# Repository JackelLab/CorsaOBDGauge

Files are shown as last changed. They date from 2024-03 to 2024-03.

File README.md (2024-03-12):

Bluetooth OBD Based Gauge For The Vauxhall/Opel Corsa

Anyone who owns an early Corsa knows you can't show the battery percentage on the dash
without having the car plugged in to a charger. The only other way is using an app on
your phone connected to and Bluetooth OBD adaptor (or WiFi adaptor if you have an iphone).

The problem with using an app (like 'Car Scanner' is that you need to connect to the
adaptor and then the car every time you want to see the data.

I decided (too long ago) that I wanted to make a display which showed the battery
percentage so it was always visible. My biggest stumbling block to this was understanding
what requests to send to the car and how to decode this data. After sometime, I found
some details on another github page 'EVNotify' which mentioned what data needed to be
sent and what the responses would be:
https://github.com/EVNotify/EVNotify/issues/205

With this information, I was finally able to get access to the data from the car.

I built a PCB with an ESP32-WROVER-IE as the main processor as it has Bluetooth built in,
a 0.96" LCD from ebay with 160 x 80 pixel 65k colours.

The features I've added so far are:

SOC        - Battery state of charge. I've used the non calibrated version, I don't know
what the differences are.

SOH        - Battery state of health. This only shows after the unit has setup and
checked communications with the OBD adaptor and car.

SOC Delta  - State of charge change. This shows to SOC change since the unit was powered
up, ideal for tracking how much battery has been used for a journey or how much battery
has been added while charging.

Temperature - Battery temperature.

Speed       - Shows the speed in 100th of MPH which can be re-calibrated if measured
against a GPS speedo.

Voltage     - OBD 12V battery voltage. Measured at the OBD adaptor.

Est. Range  - Estimated range based on speed and battery percentage used over the last
minute and 5 minutes.

There is a reed switch to change the display modes, the gauge will remember the last mode
and restore it at power up.

The ELM327 OBD.

When selecting a Bluetooth OBD adaptor, you will need to find one with the PIC18F25K80
chip. May of the adaptors for sale will say they are PIC versions, but often, they are
emulated versions and for whatever reason, the ESP32 can't communicate correctly with
them and just receives echoed data back.

So, ELM Electronics created the ELM327 chip for communicating with the OBD port on
vehicles, but with their version 1.5 software, chips where sent out without the code
protection on and so this code has been copied by may of the Chinese manufactures making
the currently available adaptors. If the adaptor you are looking to buy has any mention of
V2.1, then it is more likely a chip pretending to be a PIC.

The only way to really confirm that the adaptor has a PIC chip in it is to pop it open and
check.

My code requires you to put in the MAC address of the OBD adaptor, here are 2 ways you can
find the MAC address. Use an ESP32 to scan for Bluetooth devices and report the addresses
( https://github.com/esp32beans/ESP32-BT-exp ) or pair with a windows machine and get the
MAC address from the device details.

The alternative way, would be to use WiFi versions of the adaptor. At the moment, I've not
done any development on this method but may look into it in the future.

Another thing to note, not all adaptors have the correct resistors to do voltage
measurement and some that do, may not have been calibrated. Check the voltage with a volt
meter and compare that with the adaptor. Calibration would need to be done through a
computer with a terminal program.

Currently, the enclosure you can download is just a simple cover to hide and protect the
board, a friend is currently trying to map the instrument cluster to make a neater, almost
factory style, cover for the board which will sit to the right of the current instrument
cluster.

WIP..

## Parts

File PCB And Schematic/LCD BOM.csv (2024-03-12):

Ref | Desc | Package | Qty | PN | Manu | Notes
C1,C3-C4,C7-C8 | 100nF Capacitor 50V | 0603 | 5 | Any | Any
C2 | 10uF Capacitor 25V X5R | 0603 | 1 | Any | Any
C5-C6 | 22uF Capacitor 6.3V X5R | 0603 | 2 | Any | Any
CON1 | 3 Way RA Pin Header |  | 1 | TSM-102-01-T-SH | Samtec | Can solder wires to pads instead
CON2 | Tag 6 Pin Programming Header |  | NF
IC1 | 3.3V FixedBuck Regulator | TSOT-26-6 | 1 | AP63203WU-7 | Diodes Inc
L1 | 6.8uH Inductor |  | 1 | LQH3NPN6R8MMEL | MURATA | Or equivelent with same footprint
LCD1 | ST7735 0.96" 160x80 Pixel LCD (Solder Type) |  | 1 | LH096NT-IG11G | Limito | Soldered direct to the board
MOD1 | ESP32-Wrover |  | 1 | ESP32-WROVER-IE 8MB | Expressif
R1-R6,R8 | 10K 1% Resistor | 0603 | 7 | Any | Any
R7 | 1K 1% Resistor | 0603 | 1 | Any | Any
R9 | 10R 1% Resistor | 0603 | 1 | Any | Any
Rx | 0R Link | 0201 | 1 | Any | Any | Used to replace the link on the ESP32 Module
SW1 | Reed Switch |  | 1 | MASM-14R-10-15 | Littelfuse
TR1-TR2 | N-Channel Power MOSFET | SOT23 | 2 | DMG2302U-7 | Dides Inc

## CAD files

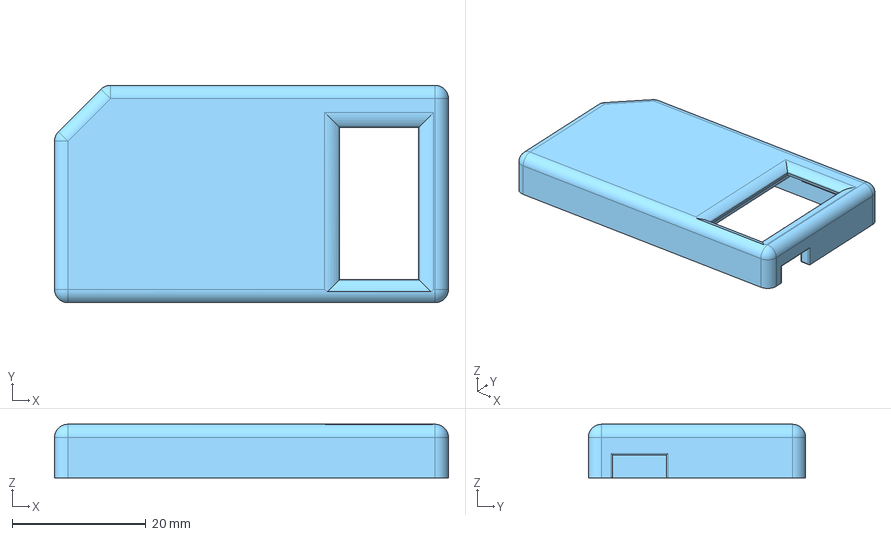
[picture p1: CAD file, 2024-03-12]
3D Files/Corsa Gauge.stp
58.8 x 32.5 x 8.00 mm

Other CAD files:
3D Files/Corsa Gauge.stl

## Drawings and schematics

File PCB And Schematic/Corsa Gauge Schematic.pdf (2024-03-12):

# 0V⁺³V³

A

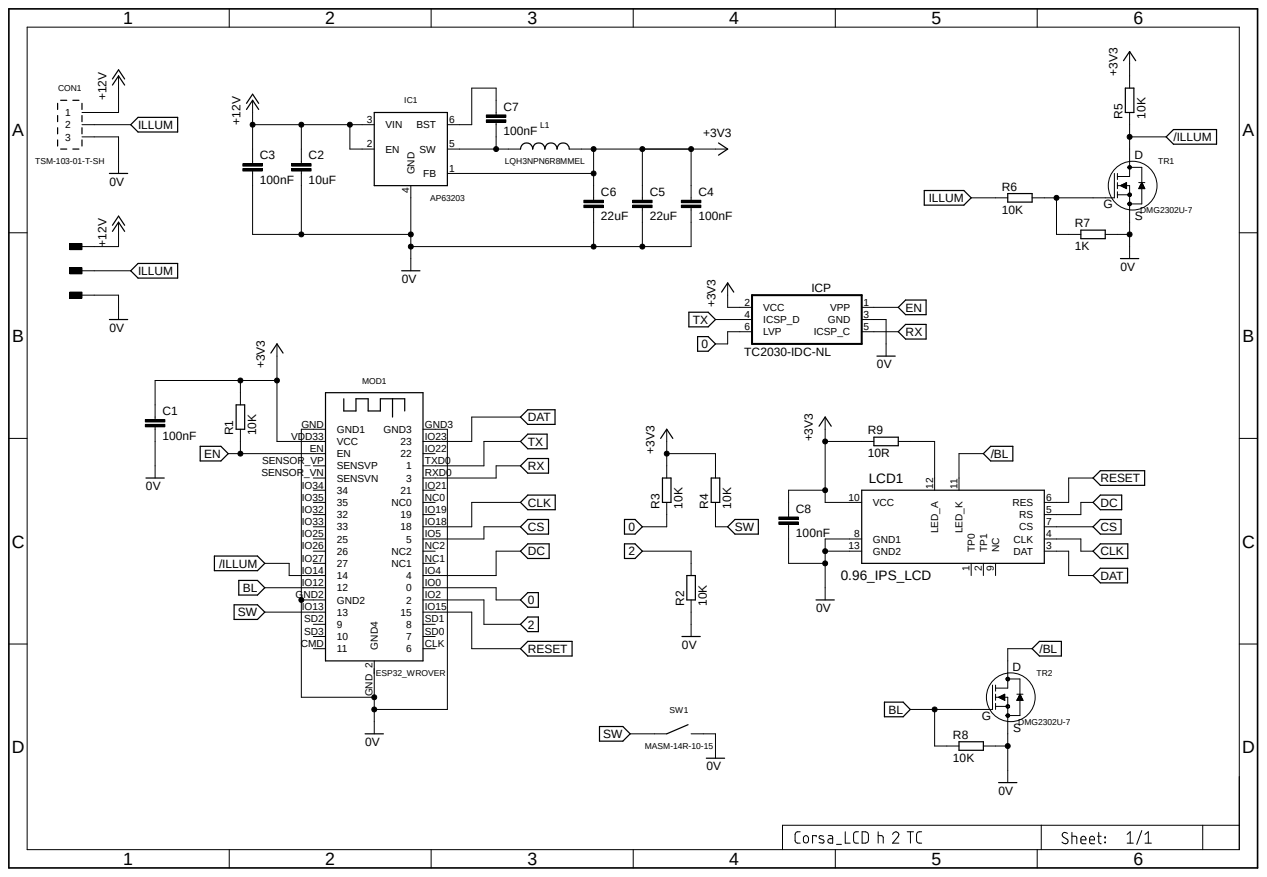
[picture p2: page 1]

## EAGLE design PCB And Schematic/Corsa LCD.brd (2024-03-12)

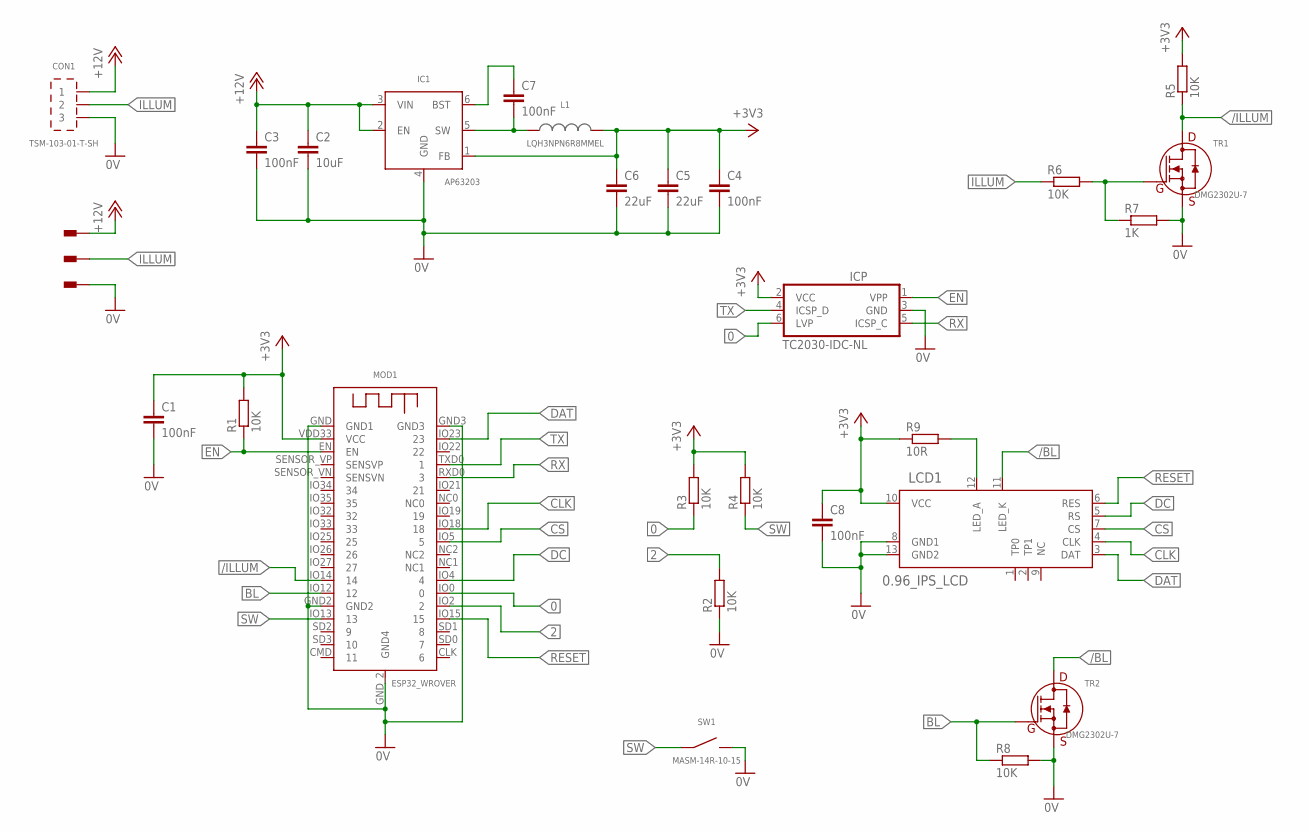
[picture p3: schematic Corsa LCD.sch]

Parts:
C1, C3, C4, C7, C8: 100nF; C0603
C2: 10uF; C0603
C5, C6: 22uF; C0603
CON1: TSM-103-01-T-SH
IC1: AP63203; TSOT26
ICP: TC2030-IDC-NL
L1: LQH3NPN6R8MMEL; LQH3NPN
LCD1: 0.96_IPS_LCD
MOD1: ESP32_WROVER; ESP32_WROOVER
PIN1, PIN2, PIN3: SOLDERPAD
R1, R2, R3, R4, R5, R6, R8: 10K; R0603
R7: 1K; R0603
R9: 10R; R0603
SW1: MASM-14R-10-15; MASM-14
TR1, TR2: DMG2302U-7; SOT23

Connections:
0: ICP.6 (LVP), MOD1.IO0 (0), R3.1
0V: C1.2, C2.2, C3.2, C4.2, C5.2, C6.2, C8.2, CON1.3, IC1.4 (GND), ICP.3 (GND), LCD1.8 (GND1), LCD1.13 (GND2), MOD1.GND (GND1), MOD1.GND2, MOD1.GND3, MOD1.GND_2 (GND4), PIN3.1, R2.1, R7.2, R8.2, SW1.2, TR1.2 (S), TR2.2 (S)
2: MOD1.IO2 (2), R2.2
+3V3: C1.1, C4.1, C5.1, C6.1, C8.1, IC1.1 (FB), ICP.2 (VCC), L1.2, LCD1.10 (VCC), MOD1.VDD33 (VCC), R1.2, R3.2, R4.2, R5.2, R9.1
+12V: C2.1, C3.1, CON1.1, IC1.2 (EN), IC1.3 (VIN), PIN1.1
/BL: LCD1.11 (LED_K), TR2.3 (D)
/ILLUM: MOD1.IO14 (14), R5.1, TR1.3 (D)
BL: MOD1.IO12 (12), R8.1, TR2.1 (G)
CLK: LCD1.4 (CLK), MOD1.IO18 (18)
CS: LCD1.7 (CS), MOD1.IO5 (5)
DAT: LCD1.3 (DAT), MOD1.IO23 (23)
DC: LCD1.5 (RS), MOD1.IO4 (4)
EN: ICP.1 (VPP), MOD1.EN, R1.1
ILLUM: CON1.2, PIN2.1, R6.1
unnamed: LCD1.12 (LED_A), R9.2
unnamed: R6.2, R7.1, TR1.1 (G)
unnamed: C7.1, IC1.6 (BST)
unnamed: C7.2, IC1.5 (SW), L1.1
RESET: LCD1.6 (RES), MOD1.IO15 (15)
RX: ICP.5 (ICSP_C), MOD1.RXD0 (3)
SW: MOD1.IO13 (13), R4.1, SW1.1
TX: ICP.4 (ICSP_D), MOD1.TXD0 (1)

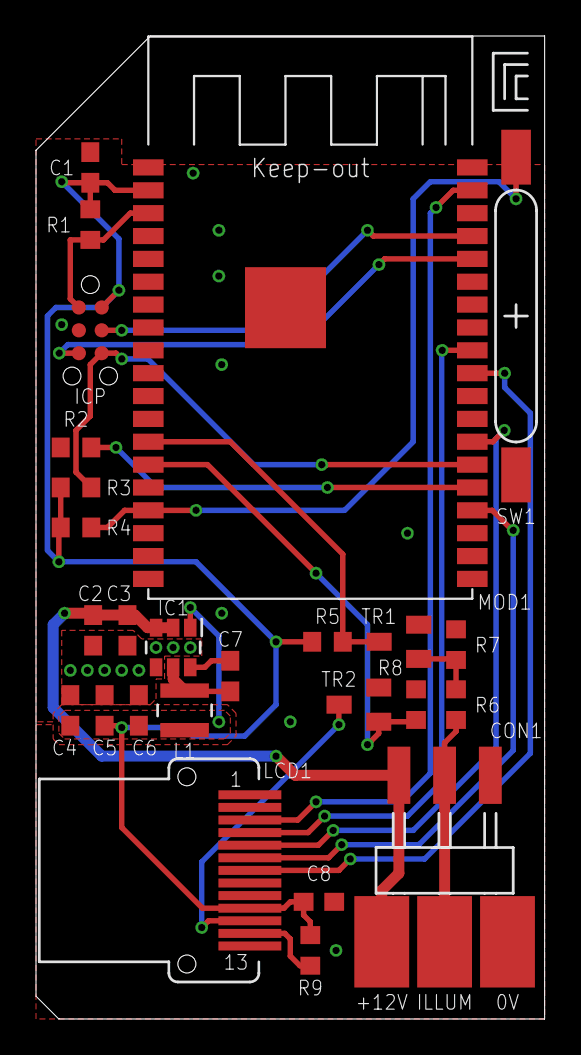
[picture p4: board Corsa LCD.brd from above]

Board: 2 copper layers, 28.3 x 54.6 mm, 29 parts (0 on the bottom side), 22 nets.

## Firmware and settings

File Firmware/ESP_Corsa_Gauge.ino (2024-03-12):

// ======================================================================================
// 
//          ESP32 Based Corsa-e Battery SOC Gauge And More Created By C. Curtis
// https://github.com/JackelLab/CorsaOBDGauge
//
// Copyright (c) 2024 C.Curtis/JackelLab
//
// I offer these files for you to use, for personal use, free of charge. You may copy
// these files, modify and reupload these files providing you are not using them for
// financial gain and must include the header and details of where the original files
// maybe downloaded.
//
// Anyone wishing to use these files for financial gain, must request permission to do so.
//
// The libraries used within the software are copyright by their relevant owners and
// separate permission will have to be gained through them.
//
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
// ======================================================================================


// ======================================================================================
// Version
// ======================================================================================
// beta - First release to github

// ======================================================================================
// Possible Future Features
// ======================================================================================
// Select between SOC and SOC calibrated
// Journey based range estimate
// Reset delta without having to turn power off
// Software selection of bluetooth MAC address instead of hard coding or automatic search

// ======================================================================================
// Options
// ======================================================================================

#define BackLightDim 127    // PWM level when illumination input is high
#define BackLightBright 255 // PWM level when illumination input is low
#define SOHDelay 1200       // Delay time to allow SOH to be seen
#define RefreshPeriod 1000  // Time in mS for main loop

#define BTMODULE 1          // 0 - No BT module, 1 - BT module
#define DEMOMODE 0          // 0 - Normal mode, 1 - Demo mode

// When demomode = 1, use the following values at the start
#define DemoSOH 87.6;
#define DemoSOC 91.01;
#define DemoSOCDelta 100.0;
#define DemoTemperature 12;
#define DemoVoltage 13.8;
#define DemoSpeed 0.0;

#define LCDOrientation 1    // 1 is newer PCB, 3 is older (aplha) PCB

#define SpeedCorrection 208

// --------------------------------------------------------------------------------------
// Colour Options
// --------------------------------------------------------------------------------------

#define SOCGood TFT_WHITE
#define SOCOk TFT_YELLOW
#define SOCBad TFT_RED
#define SOCOkLevel 10
#define SOCBadLevel 2

#define TempHot TFT_RED
#define TempCaution 0xFFE0              // Yellow
#define TempOk TFT_WHITE
#define TempCold 0x03FF                 // Cyanish blue
#define TempHotLevel 50
#define TempCautionLevel 40
#define TempColdLevel 2

#define DeltaSOCPlus TFT_GREEN
#define DeltaSOCNegative 0xFC10         // Whiter red

#define SOHGood TFT_WHITE
#define SOHOk TFT_WHITE
#define SOHBad TFT_YELLOW
#define SOHFlagPole TFT_WHITE
#define SOHFlagColour TFT_BLUE
#define SOHOkLevel 80
#define SOHBadLevel 50

#define VoltageHigh TFT_RED
#define VoltageCautionHigh TFT_YELLOW
#define VoltageGood TFT_GREEN
#define VoltageOk TFT_WHITE
#define VoltageLow TFT_YELLOW
#define VoltageLowBad TFT_RED
#define VoltageHighLevel 15.0
#define VoltageCautionHighLevel 14.6
#define VoltageOkLevel 13.8
#define VoltageLowLevel 12.5
#define VoltageLowBadLevel 12.0

#define InvalidDataColour TFT_RED

// Colours are a 16 bit number in the format of 5-6-5. 5 red bits, 6 green and 5 blue.
// Red is 0xF800, green is 0x07E0, blue is 0x001F

// ======================================================================================
// Includes
// ======================================================================================

#include <Arduino.h>
#include "SPI.h"
#include "TFT_eSPI.h"
#include "Free_Fonts.h"

#include "Icons.h"

// EEPROM include and definitions
#include <EEPROM.h>
#define EEPROM_SIZE 64

// ======================================================================================
// Definitions
// ======================================================================================

// Use hardware SPI
TFT_eSPI tft = TFT_eSPI();
TFT_eSprite page = TFT_eSprite(&tft);

// Bluetooth setup
#if BTMODULE == 1
// Bluetooth includes
#include "BluetoothSerial.h"
BluetoothSerial SerialBT;
uint8_t OBDAddress[6]  = {0x01, 0x02, 0x03, 0x04, 0x05, 0x06};  // OBD MAC address
#endif

// Test positions
#define ROW1L 36
#define ROW2L 76
#define ROW2S 73

#define NoOfModes 9
// Modes:
// 0 - TL = SOC, BL = Temperature and SOC Delta
// 1 - TL = SOC, BL = Range 1 and SOC Delta
// 2 - TL = SOC, BL = Range 1 and Speed
// 3 - TL = SOC, BL = Temperature and Speed
// 4 - TL = SOC, BL = Range 1 and Range 5
// 5 - TL = SOC, BL = Temperature and 12V Battery
// 6 - TL = SOC, BL = 12V Battery and SOC Delta
// 7 - TL = SOC, BL = 12V Battery and Speed
// 8 - TL = SOC, BL = Speed

// Distance covered by traveling at 1mph for 1 second
#define SpeedFactor 0.000277777

// ======================================================================================
// Icon Location Definitions (Splash Screen)
// ======================================================================================

#define BTx 68
#define BTy 20
#define CPUx 0
#define CPUy 24
#define CARx 128
#define CARy 24

// ======================================================================================
// IO defintions
// ======================================================================================

#define BackLight 12      // LCD Backlight output pin
#define Button 13         // Reed switch input
#define Illumination 14   // Illumination control input

// ======================================================================================
// Comms Details
// ======================================================================================

#define CommsTimeOut 3000                   // Time in mS (General comms timeout)
#define SearchingTimeOut 10000              // Time in mS (timeout after issuing a reset)

// ======================================================================================
// Variables
// ======================================================================================

#if DEMOMODE == 1
// Demo mode variables with preset values
float SOC = DemoSOC;
int SOCDemoMode = 0;
float StartSOC = DemoSOCDelta;
float SOH = DemoSOH;
bool SOHFlag = true;
uint16_t Speed;
float SpeedF = DemoSpeed;
int Temperature = DemoTemperature;
float BatteryVoltage = DemoVoltage;
bool SpeedDirection = false;
#else
float SOC;
float StartSOC;
float SOH;
bool SOHFlag = false;
uint16_t Speed;
float SpeedF;
int Temperature;
float BatteryVoltage;
#endif

char ReceiveBuff[48];     // Buffer has to be big enough to hold
                          //  SEARCHING... dUNABLE TO CONNECT dd>
uint8_t ReceiveBuffCount = 0;

float dSOC;
bool LastBacklight;
bool IlluminationInput;
bool Stuck;
uint16_t tp;
bool Timeout;
bool ValidData;
unsigned long LastUpdate;

bool ModeChange = false;
bool ModeChangeInput;
uint8_t Mode = 0;
bool UseEEPROM;

float BufferD[300];
float BufferP[300];
uint16_t Pointer1 = 0;
uint16_t Pointer5 = 0;
uint16_t PointerMax = 0;
float Distance1 = 0.0;
float Distance5 = 0.0;
float Percent1 = 0.0;
float Percent5 = 0.0;
float Range1;
float Range5;
int Range;
float t;
uint16_t n;

// ======================================================================================
// Main Routine
// ======================================================================================

void setup()
{
  // Use serial for debugging and logging
  Serial.begin(115200);
  
  // Setup IO
  //pinMode(Button, INPUT);
  pinMode(Button, INPUT_PULLUP);
  pinMode(Illumination, INPUT);
  
  // Setup LCD using TFT eSPI
  tft.init();
  tft.setRotation(LCDOrientation);  // 3 is older design, 1 is newer design
  tft.fillScreen(TFT_BLACK);
  tft.setTextSize(1);

  // Setup backlight using PWM
  ledcSetup(1, 1000, 8);        // Setup PWM channel
  ledcAttachPin(BackLight, 1);  // Assign backlight to channel
  // Check Illumination input and set backlight as approprate
  if(digitalRead(Illumination) == LOW)
  {
    ledcWrite(1, BackLightDim);
    LastBacklight = true;
  }
  else
  {
    ledcWrite(1, BackLightBright);
    LastBacklight = false;
  }

  // Load last mode from EEPROM 
  if(!EEPROM.begin(EEPROM_SIZE))
  {
    // Starting EEPROM failed so don't use it
    UseEEPROM = false;
  }
  else
  {
    UseEEPROM = true;
    // Is the EEPROM already setup?
    if((uint8_t) EEPROM.read(0) != 'M')
    {
      // EEPROM is not setup
      EEPROM.write(0, 'M');
      EEPROM.write(1, Mode);
      EEPROM.commit();
    }
    Mode = EEPROM.read(1);
  }
  
  // Setup page for quick drawing on the LCD
  //page.setAttribute(PSRAM_ENABLE, true);
  page.createSprite(160, 80);
  
  // Draw icon's and a bar showing communication point
  //tft.fillScreen(TFT_BLACK);
  tft.pushImage(BTx, BTy, 25, 39, BT_G, TFT_BLACK);
  tft.pushImage(CPUx, CPUy, 32, 32, CPU, TFT_BLACK);
  tft.pushImage(CARx, CARy, 32, 32, CAR, TFT_BLACK);
  tft.fillRect(CPUx + 34, 38, BTx - CPUx - 36, 4, TFT_WHITE);
  
#if BTMODULE == 1
  // Bluetooth serial and ODB stuff
  SerialBT.setPin("1234");
  SerialBT.begin("Corsa-e", true);
  
  // Try and connect to OBD via bluetooth serial
  Stuck = true;
  while(Stuck)
  {
    if(!SerialBT.connect(OBDAddress))
    {
      // Can't connect to OBDII device, show message.
      tft.pushImage(BTx, BTy, 25, 39, BT_R, TFT_BLACK);
      tft.fillRect(CPUx + 34, 38, BTx - CPUx - 36, 4, TFT_RED);
      delay(1000);
    }
    else
    {
      // Connected, exit the loop
      Stuck = false;
    }
  }
  // Show that chip to BT module is successful
  tft.fillRect(CPUx + 34, 38, BTx - CPUx - 36, 4, TFT_GREEN);
  Serial.println("BT Connected");
  // BT icon to blue
  tft.pushImage(BTx, BTy, 25, 39, BT_B, TFT_BLACK);
  // Show new communication point, BT to car
  tft.fillRect(BTx + 27, 38, CARx - BTx - 29, 4, TFT_WHITE);
  
  // Communicate with OBD II, start with reset command
  Stuck = true;
  while(Stuck)
  {
    Timeout = SendOBD("ATZ", SearchingTimeOut);
    if(ReceiveBuffCount == 0 || Timeout)
    {
      // Couldn't talk to ELM327
      // Show red bluetooth icon?
      //tft.pushImage(BTx, BTy, 25, 39, BT_R, TFT_BLACK);
      // Show red line
      tft.fillRect(BTx + 27, 38, CARx - BTx - 29, 4, TFT_RED);
      delay(2000);
    }
    else
    {
      Stuck = false;
    }
  }
  // Clear the line to show communication steps
  tft.fillRect(BTx + 27, 38, CARx - BTx - 29, 4, TFT_BLACK);
  
  // Setup and start OBD
  Timeout = SendOBD("ATE0", CommsTimeOut);    // Echo off
  tft.fillRect(BTx + 27, 38, 2, 4, TFT_GREEN);
  
  Timeout = SendOBD("ATH1", CommsTimeOut);    // Headers on
  tft.fillRect(BTx + 30, 38, 2, 4, TFT_GREEN);
  
  Timeout = SendOBD("ATS0", CommsTimeOut);    // Spaces off
  tft.fillRect(BTx + 33, 38, 2, 4, TFT_GREEN);
  
  Timeout = SendOBD("ATM0", CommsTimeOut);    // Memory off
  tft.fillRect(BTx + 36, 38, 2, 4, TFT_GREEN);
  
  Timeout = SendOBD("ATSPA6", CommsTimeOut);   // Protocol automatic 6
  tft.fillRect(BTx + 39, 38, 2, 4, TFT_GREEN);
  
  Timeout = SendOBD("ATAT1", CommsTimeOut);    // Adaptive timing auto1
  tft.fillRect(BTx + 42, 38, 2, 4, TFT_GREEN);
  
  Timeout = SendOBD("ATSH6B4", CommsTimeOut);    // Set header 6B4 (this has SOC and SOH)
  tft.fillRect(BTx + 45, 38, 2, 4, TFT_GREEN);
  
  Timeout = SendOBD("ATFCSH6B4", CommsTimeOut);    // Flow control set header 6B4
  tft.fillRect(BTx + 48, 38, 2, 4, TFT_GREEN);
  
  Timeout = SendOBD("ATFCSD300000", CommsTimeOut);    // Set data to 300000
  tft.fillRect(BTx + 51, 38, 2, 4, TFT_GREEN);
  
  Timeout = SendOBD("ATFCSM1", CommsTimeOut);    // Flow control mode 1
  tft.fillRect(BTx + 54, 38, 2, 4, TFT_GREEN);
  
  Timeout = SendOBD("ATCRA694", CommsTimeOut);    // Receive address 694
#endif
#if DEMOMODE == 0
  // Get SOC
  Timeout = SendOBD("22D410", CommsTimeOut);    // Request SOC
  // Reply example 6940562D410ABA8dd>
  ValidData = true;
  // Check reply is valid
  if(ReceiveBuff[8] == 0x34 && ReceiveBuff[9] == 0x31 && ReceiveBuff[10] == 0x30 && Timeout == false)
  {
    // Valid data
    tp = Hex2Dec(ReceiveBuff[11], ReceiveBuff[12]);
    tp = (tp * 256) + Hex2Dec(ReceiveBuff[13], ReceiveBuff[14]);
    SOC = ((float) tp) / 512.0;
  }
  else
  {
    // Invalid data
    SOC = 0.0;
    ValidData = false;
  }
  // Copy SOC for delta SOC
  StartSOC = SOC;
  
  // Get SOH (we will only show this once)
  Timeout = SendOBD("22D860", CommsTimeOut);    // Request SOH
  // Reply example 6940562D8600105EDdd>
  // Check reply is valid
  if(ReceiveBuff[8] == 0x38 && ReceiveBuff[9] == 0x36 && ReceiveBuff[10] == 0x30 && Timeout == false)
  {
    // Valid data
    tp = Hex2Dec(ReceiveBuff[13], ReceiveBuff[14]);
    tp = (tp * 256) + Hex2Dec(ReceiveBuff[15], ReceiveBuff[16]);
    SOH = ((float) tp) / 16.0;
    if(ReceiveBuff[12] != 0x30)
    {
      SOHFlag = true;
      // Not sure what this flag is for
    }
  }
  else
  {
    // Invalid data
    SOH = 0.0;
    ValidData = false;
  }

  // Switch to 6A2/682 for battery temperature
  Timeout = SendOBD("ATSH6A2", CommsTimeOut);    // Set header 6A2
  Timeout = SendOBD("ATFCSH6A2", CommsTimeOut);    // Flow control set header 6A2
  Timeout = SendOBD("ATCRA682", CommsTimeOut);    // Receive address 682
  
  // Get battery temperature
  Timeout = SendOBD("22D8EF", CommsTimeOut);    // Request Temperature
  // Check if reply is valid
  if(ReceiveBuff[8] == 0x38 && ReceiveBuff[9] == 0x45 && ReceiveBuff[10] == 0x46 && Timeout == false)
  {
    // Valid data
    Temperature = (int) (Hex2Dec(ReceiveBuff[11], ReceiveBuff[12]));
    // If bit 7 is set (128-255), it's negative
    if(Temperature > 127)
    {
      // Make it negative
      Temperature = Temperature - 256;
    }
  }
  else
  {
    // Invalid data
    Temperature = 0;
    ValidData = false;
  }
#else
  tft.fillRect(BTx + 27, 38, CARx - BTx - 29, 4, TFT_GREEN);
  delay(500);
  ValidData = true;
#endif
    
  // If we have valid data, show the SOH
  if(ValidData == true)
  {
    DisplaySOH();
  }
  else
  {
    DisplayBadData();
  }
  // Delay for a moment so SOH can be read
  delay(SOHDelay);
}

// ======================================================================================
// Main Loop
// ======================================================================================

void loop()
{
  // Update loop delay
  LastUpdate = millis();
  ValidData = true;
  
#if DEMOMODE == 0
  // Switch to 6B4/694
  Timeout = SendOBD("ATSH6B4", CommsTimeOut);    // Set header 6B4
  Timeout = SendOBD("ATFCSH6B4", CommsTimeOut);    // Flow control set header 6B4
  Timeout = SendOBD("ATCRA694", CommsTimeOut);    // Receive address 694
  // Set SOC
  Timeout = SendOBD("22D410", CommsTimeOut);    // Request SOC
  if(ReceiveBuff[8] == 0x34 && ReceiveBuff[9] == 0x31 && ReceiveBuff[10] == 0x30 && Timeout == false)
  {
    // Valid data
    tp = Hex2Dec(ReceiveBuff[11], ReceiveBuff[12]);
    tp = (tp * 256) + Hex2Dec(ReceiveBuff[13], ReceiveBuff[14]);
    SOC = ((float) tp) / 512.0;
  }
  else
  {
    // Invalid data
    SOC = 0.0;
    ValidData = false;
  }
  
  // Switch to 6A2/682
  Timeout = SendOBD("ATSH6A2", CommsTimeOut);    // Set header 6A2
  Timeout = SendOBD("ATFCSH6A2", CommsTimeOut);    // Flow control set header 6A2
  Timeout = SendOBD("ATCRA682", CommsTimeOut);    // Receive address 682
  // Get battery temperature
  Timeout = SendOBD("22D8EF", CommsTimeOut);    // Request Temperature
  if(ReceiveBuff[8] == 0x38 && ReceiveBuff[9] == 0x45 && ReceiveBuff[10] == 0x46 && Timeout == false)
  {
    // Valid data
    Temperature = (int) (Hex2Dec(ReceiveBuff[11], ReceiveBuff[12]));
    if(Temperature > 127)
    {
      // Make it negative
      Temperature = Temperature - 256;
    }
  }
  else
  {
    // Invalid data
    Temperature = 0;
    ValidData = false;
  }
  
  // Speed
  Timeout = SendOBD("22D402", CommsTimeOut);    // Request Temperature
  if(ReceiveBuff[8] == 0x34 && ReceiveBuff[9] == 0x30 && ReceiveBuff[10] == 0x32 && Timeout == false)
  {
    // Valid data
    Speed = ((uint16_t) (Hex2Dec(ReceiveBuff[11], ReceiveBuff[12]))) << 8;
    Speed = Speed + (uint16_t) (Hex2Dec(ReceiveBuff[13], ReceiveBuff[14]));
    SpeedF = ((float) Speed) / SpeedCorrection;
  }
  else
  {
    // Invalid data
    Speed = 0;
    SpeedF = 0.0;
    ValidData = false;
  }
  
  // Get 12V battery voltage
  Timeout = SendOBD("ATRV", CommsTimeOut);    // Request vattery voltage
  if(ReceiveBuff[ReceiveBuffCount - 3] != 'V' || Timeout == true)
  {
    // Incorrect response
    BatteryVoltage == 1.2;
  }
  else
  {
    if(ReceiveBuffCount == 7)
    {
      // Result is >= 10.0V
      BatteryVoltage = (float)((ReceiveBuff[0] - '0') * 10) + (float)(ReceiveBuff[1] - '0') + ((float)(ReceiveBuff[3] - '0') / 10.0);
    }
    else if(ReceiveBuffCount == 6)
    {
      // Result is < 10.0V
      BatteryVoltage = (float)(ReceiveBuff[0] - '0') + ((float)(ReceiveBuff[2] - '0') / 10.0);
    }
    else
    {
      // Unknown
      BatteryVoltage = 2.3;
    }
  }
#else
  if(SOC < 90.0 && SOCDemoMode == 0)
  {
    SOCDemoMode = 1;
  }
  else if(SOC > 95.0 && SOCDemoMode == 1)
  {
    SOCDemoMode = 2;
  }
  else if(SOCDemoMode == 0 || SOCDemoMode == 2)
  {
    SOC = SOC - 0.01;
    if(SOC < 0.0)
    {
      SOC = 100.0;
      SOCDemoMode = 0;
    }
  }
  else
  {
    SOC = SOC + 0.01;
  }
  Temperature++;
  if(Temperature > 60)
  {
    Temperature = -12;
  }
  if(SpeedDirection == false)
  {
    SpeedF = SpeedF + 0.5;
  }
  else
  {
    SpeedF = SpeedF - 0.5;
  }
  if(SpeedF > 60.0)
  {
    SpeedDirection = true;
  }
  if(SpeedF < 0.0)
  {
    SpeedF = 0.0;
    SpeedDirection = false;
  }
#if BTMODULE == 1
  // Get 12V battery voltage
  Timeout = SendOBD("ATRV", CommsTimeOut);    // Request vattery voltage
  if(ReceiveBuff[ReceiveBuffCount - 3] != 'V' || Timeout == true)
  {
    // Incorrect response
    BatteryVoltage == 1.2;
  }
  else
  {
    if(ReceiveBuffCount == 7)
    {
      // Result is >= 10.0V
      BatteryVoltage = (float)((ReceiveBuff[0] - '0') * 10) + (float)(ReceiveBuff[1] - '0') + ((float)(ReceiveBuff[3] - '0') / 10.0);
    }
    else if(ReceiveBuffCount == 6)
    {
      // Result is < 10.0V
      BatteryVoltage = (float)(ReceiveBuff[0] - '0') + ((float)(ReceiveBuff[2] - '0') / 10.0);
    }
    else
    {
      // Unknown
      BatteryVoltage = 2.3;
    }
  }
#else
  BatteryVoltage = BatteryVoltage + 0.1;
  if(BatteryVoltage >= 16.0)
  {
    BatteryVoltage = 8.0;
  }
#endif
#endif
  
  // Work on buffered data
  // Shift buffer
  for(n = 299; n != 0; n--)
  {
    BufferD[n] = BufferD[n - 1];
    BufferP[n] = BufferP[n - 1];
  }
  // Save new data
  BufferD[0] = SpeedF;
  BufferP[0] = SOC;
  // Calculate ranges
  t = 0.0;
  for(n = 0; n != Pointer1; n++)
  {
    t = t + BufferD[n];
  }
  Distance1 = t * SpeedFactor;
  t = 0.0;
  for(n = 0; n != Pointer5; n++)
  {
    t = t + BufferD[n];
  }
  Distance5 = t * SpeedFactor;
  Percent1 = BufferP[Pointer1] - BufferP[0];
  Percent5 = BufferP[Pointer5] - BufferP[0];
  
  // CAUTION, need to do divide by zero check!!!!
  if(Distance1 != 0.0 && Percent1 != 0.0)
  {
    if(Percent1 < 0.0)
    {
      Range1 = 999.0;
    }
    else
    {
      Range1 = Distance1 / Percent1 * BufferP[0];
    }
  }
  else if(Distance1 == 0.0)
  {
    Range1 = 0.0;
  }
  else
  {
    Range1 = 999.0;
  }
  if(Distance5 != 0.0 && Percent5 != 0.0)
  {
    if(Percent5 < 0.0)
    {
      Range5 = 999.0;
    }
    else
    {
      Range5 = Distance5 / Percent5 * BufferP[0];
    }
  }
  else if(Distance5 == 0.0)
  {
    Range5 = 0.0;
  }
  else
  {
    Range5 = 999.0;
  }
  if(Pointer1 != 59)
  {
    Pointer1++;
  }
  if(Pointer5 != 299)
  {
    Pointer5++;
  }
  
  // If we have valid data, display it, otherwise all ----
  if(ValidData == true)
  {
    DisplayReadings();
  }
  else
  {
    DisplayBadData();
  }
  
  // Loop delay, while in the loop, check for a low on the backlight input
  //  (could be a PWM input) or the magnetic switch (mode change)
  IlluminationInput = false;
  ModeChangeInput = false;
  if(digitalRead(Button) == HIGH && ModeChange == true)
  {
    ModeChange = false;
  }

  while((LastUpdate + RefreshPeriod) > millis())
  {
    if(digitalRead(Illumination == LOW))
    {
      IlluminationInput = true;
    }
    if(digitalRead(Button) == LOW)
    {
      ModeChangeInput = true;
    }
  }
  
  // Check if the backlight has changed
  if(IlluminationInput == true && LastBacklight == false)
  {
    // Dim backlight
    ledcWrite(1, BackLightDim);
    LastBacklight = true;
  }
  if(IlluminationInput == false && LastBacklight == true)
  {
    // Full brightness
    ledcWrite(1, BackLightBright);
    LastBacklight = false;
  }
  
  // Check if the reed switch is activated to change the mode
  if(ModeChangeInput == true && ModeChange == false)
  {
    Mode++;
    if(Mode == NoOfModes)
    {
      Mode = 0;
    }
    ModeChange = true;
    // Save changes to EEPROM?
    if(UseEEPROM == true)
    {
      EEPROM.write(1, Mode);
      EEPROM.commit();
    }
  }
  else if(ModeChangeInput == false && ModeChange == true)
  {
    ModeChange = false;
  }
}

// ======================================================================================
// Display Routines
// ======================================================================================
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

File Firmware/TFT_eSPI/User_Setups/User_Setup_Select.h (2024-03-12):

// This header file contains a list of user setup files and defines which one the
// compiler uses when the IDE performs a Verify/Compile or Upload.
//
// Users can create configurations for different boards and TFT displays.
// This makes selecting between hardware setups easy by "uncommenting" one line.

// The advantage of this hardware configuration method is that the examples provided
// with the library should work with immediately without any other changes being
// needed. It also improves the portability of users sketches to other hardware
// configurations and compatible libraries.
//
// Create a shortcut to this file on your desktop to permit quick access for editing.
// Re-compile and upload after making and saving any changes to this file.

// Customised User_Setup files are stored in the "User_Setups" folder.

// It is also possible for the user tft settings to be included with the sketch, see
// the "Sketch_with_tft_setup" generic example. This may be more convenient for
// multiple projects.

#ifndef USER_SETUP_LOADED //  Lets PlatformIO users define settings in
                          //  platformio.ini, see notes in "Tools" folder.

///////////////////////////////////////////////////////
//   User configuration selection lines are below    //
///////////////////////////////////////////////////////

// Only ONE line below should be uncommented to define your setup.  Add extra lines and files as needed.

#include <User_Setup.h>           // Default setup is root library folder


// ESP32 with ebay LCD 160x80
#include <User_Setups/Setup204_ST7735_160x80.h>


#endif // USER_SETUP_LOADED



/////////////////////////////////////////////////////////////////////////////////////
//                                                                                 //
//     DON'T TINKER WITH ANY OF THE FOLLOWING LINES, THESE ADD THE TFT DRIVERS     //
//       AND ESP8266 PIN DEFINITONS, THEY ARE HERE FOR BODMER'S CONVENIENCE!       //
//                                                                                 //
/////////////////////////////////////////////////////////////////////////////////////


// Identical looking TFT displays may have a different colour ordering in the 16 bit colour
#define TFT_BGR 0   // Colour order Blue-Green-Red
#define TFT_RGB 1   // Colour order Red-Green-Blue

// Legacy setup support, RPI_DISPLAY_TYPE replaces RPI_DRIVER
#if defined (RPI_DRIVER)
  #if !defined (RPI_DISPLAY_TYPE)
    #define RPI_DISPLAY_TYPE
  #endif
#endif

// Legacy setup support, RPI_ILI9486_DRIVER form is deprecated
// Instead define RPI_DISPLAY_TYPE and also define driver (e.g. ILI9486_DRIVER) 
#if defined (RPI_ILI9486_DRIVER)
  #if !defined (ILI9486_DRIVER)
    #define ILI9486_DRIVER
  #endif
  #if !defined (RPI_DISPLAY_TYPE)
    #define RPI_DISPLAY_TYPE
  #endif
#endif

// Invoke 18 bit colour for selected displays
#if !defined (RPI_DISPLAY_TYPE) && !defined (TFT_PARALLEL_8_BIT) && !defined (TFT_PARALLEL_16_BIT) && !defined (ESP32_PARALLEL)
  #if defined (ILI9481_DRIVER) || defined (ILI9486_DRIVER) || defined (ILI9488_DRIVER)
    #define SPI_18BIT_DRIVER
  #endif
#endif

// Load the right driver definition - do not tinker here !
#if   defined (ILI9341_DRIVER) || defined(ILI9341_2_DRIVER) || defined (ILI9342_DRIVER)
     #include <TFT_Drivers/ILI9341_Defines.h>
     #define  TFT_DRIVER 0x9341
#elif defined (ST7735_DRIVER)
     #include <TFT_Drivers/ST7735_Defines.h>
     #define  TFT_DRIVER 0x7735
#elif defined (ILI9163_DRIVER)
     #include <TFT_Drivers/ILI9163_Defines.h>
     #define  TFT_DRIVER 0x9163
#elif defined (S6D02A1_DRIVER)
     #include <TFT_Drivers/S6D02A1_Defines.h>
     #define  TFT_DRIVER 0x6D02
#elif defined (ST7796_DRIVER)
      #include "TFT_Drivers/ST7796_Defines.h"
      #define  TFT_DRIVER 0x7796
#elif defined (ILI9486_DRIVER)
     #include <TFT_Drivers/ILI9486_Defines.h>
     #define  TFT_DRIVER 0x9486
#elif defined (ILI9481_DRIVER)
     #include <TFT_Drivers/ILI9481_Defines.h>
     #define  TFT_DRIVER 0x9481
#elif defined (ILI9488_DRIVER)
     #include <TFT_Drivers/ILI9488_Defines.h>
     #define  TFT_DRIVER 0x9488
#elif defined (HX8357D_DRIVER)
     #include "TFT_Drivers/HX8357D_Defines.h"
     #define  TFT_DRIVER 0x8357
#elif defined (EPD_DRIVER)
     #include "TFT_Drivers/EPD_Defines.h"
     #define  TFT_DRIVER 0xE9D
#elif defined (ST7789_DRIVER)
     #include "TFT_Drivers/ST7789_Defines.h"
     #define  TFT_DRIVER 0x7789
#elif defined (R61581_DRIVER)
     #include "TFT_Drivers/R61581_Defines.h"
     #define  TFT_DRIVER 0x6158
#elif defined (ST7789_2_DRIVER)
     #include "TFT_Drivers/ST7789_2_Defines.h"
     #define  TFT_DRIVER 0x778B
#elif defined (RM68140_DRIVER)
     #include "TFT_Drivers/RM68140_Defines.h"
     #define  TFT_DRIVER 0x6814
#elif defined (SSD1351_DRIVER)
     #include "TFT_Drivers/SSD1351_Defines.h"
     #define  TFT_DRIVER 0x1351
#elif defined (SSD1963_480_DRIVER)
     #include "TFT_Drivers/SSD1963_Defines.h"
     #define  TFT_DRIVER 0x1963
#elif defined (SSD1963_800_DRIVER)
     #include "TFT_Drivers/SSD1963_Defines.h"
     #define  TFT_DRIVER 0x1963
#elif defined (SSD1963_800ALT_DRIVER)
     #include "TFT_Drivers/SSD1963_Defines.h"
     #define  TFT_DRIVER 0x1963
#elif defined (SSD1963_800BD_DRIVER)
     #include "TFT_Drivers/SSD1963_Defines.h"
     #define  TFT_DRIVER 0x1963
#elif defined (GC9A01_DRIVER)
     #include "TFT_Drivers/GC9A01_Defines.h"
     #define  TFT_DRIVER 0x9A01
#elif defined (ILI9225_DRIVER)
     #include "TFT_Drivers/ILI9225_Defines.h"
     #define  TFT_DRIVER 0x9225
#elif defined (RM68120_DRIVER)
     #include "TFT_Drivers/RM68120_Defines.h"
     #define  TFT_DRIVER 0x6812
#elif defined (HX8357B_DRIVER)
     #include "TFT_Drivers/HX8357B_Defines.h"
     #define  TFT_DRIVER 0x835B
#elif defined (HX8357C_DRIVER)
     #include "TFT_Drivers/HX8357C_Defines.h"
     #define  TFT_DRIVER 0x835C

                              // <<<<<<<<<<<<<<<<<<<<<<<< ADD NEW DRIVER HERE
                              // XYZZY_init.h and XYZZY_rotation.h must also be added in TFT_eSPI.cpp
#elif defined (XYZZY_DRIVER)
     #include "TFT_Drivers/XYZZY_Defines.h"
     #define  TFT_DRIVER 0x0000
#else
     #define  TFT_DRIVER 0x0000
#endif

// These are the pins for ESP8266 boards
//      Name   GPIO    NodeMCU      Function
#define PIN_D0  16  // GPIO16       WAKE
#define PIN_D1   5  // GPIO5        User purpose
#define PIN_D2   4  // GPIO4        User purpose
#define PIN_D3   0  // GPIO0        Low on boot means enter FLASH mode
#define PIN_D4   2  // GPIO2        TXD1 (must be high on boot to go to UART0 FLASH mode)
#define PIN_D5  14  // GPIO14       HSCLK
#define PIN_D6  12  // GPIO12       HMISO
#define PIN_D7  13  // GPIO13       HMOSI  RXD2
#define PIN_D8  15  // GPIO15       HCS    TXD0 (must be low on boot to enter UART0 FLASH mode)
#define PIN_D9   3  //              RXD0
#define PIN_D10  1  //              TXD0
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
